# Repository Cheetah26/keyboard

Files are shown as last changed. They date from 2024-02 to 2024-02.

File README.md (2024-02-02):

# keyboard
My fully custom split keyboard

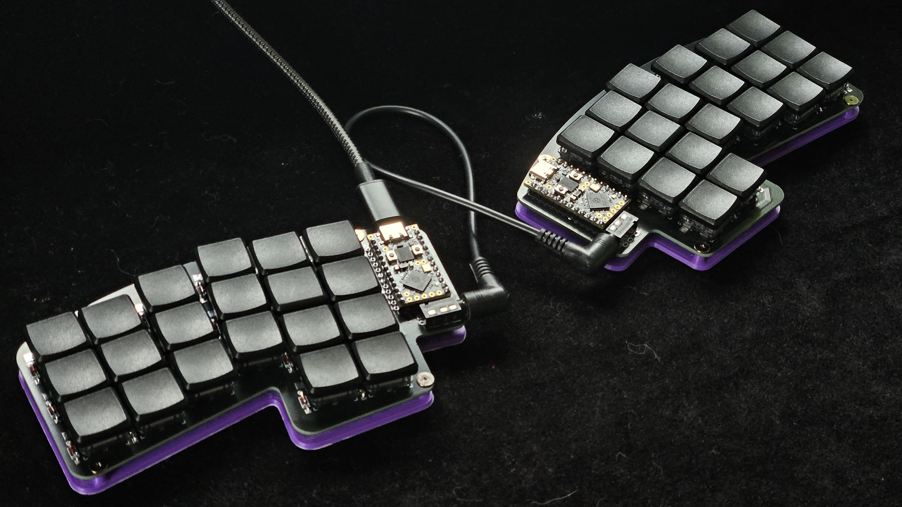
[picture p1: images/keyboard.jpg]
keyboard glamor shot


## Features
- 40 key split layout
- dual rp2040 microcontrollers
- [kmk](http://kmkfw.io) firmware
- stenography layer for [plover](http://www.openstenoproject.org/)
- 3d printed base

## Background / design 
After years of wanting an ergonomic split keyboard but never seeing one that perfectly matched what I imagined in my mind, I decided to design and build my own!

I started completely from scratch by putting my hand on a sheet of paper and just seeing where my fingers liked to be. From there I made a layout based on where keys could actually go, and iterated until things really felt right.

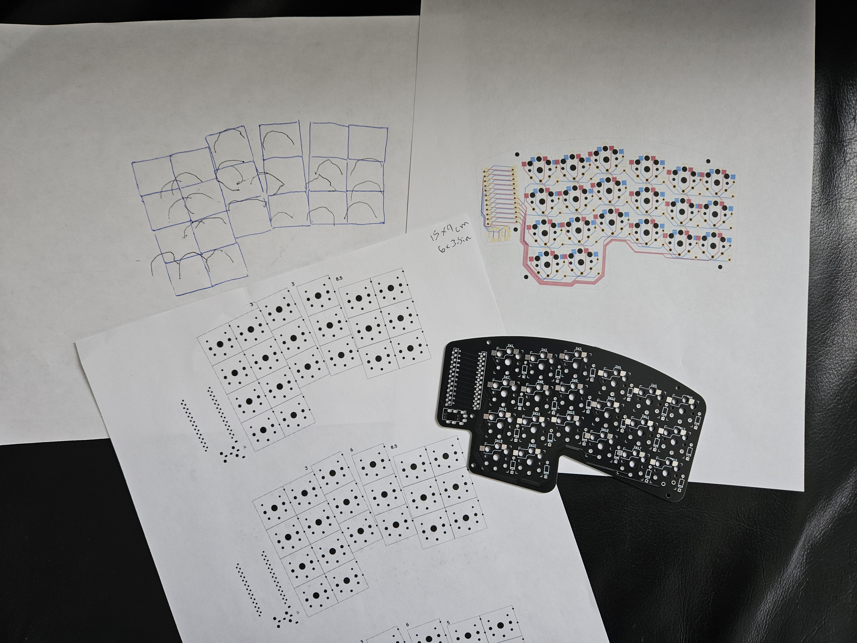
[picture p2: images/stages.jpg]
paper printouts of my PCB design at various stages next to the final PCB


I laid out the PCB according to this design, ordered all the parts, and anxiously waited to find out what I messed up. Since this was my first time designing a PCB, fist time programming a microcontroller, and first big soldering project, I 100% expected something to go wrong. To my surprise, the only issue was that I forgot to account for the size of the jack connecting each half. After a little sanding, everything went together perfectly and now I couldn't be happier with it.

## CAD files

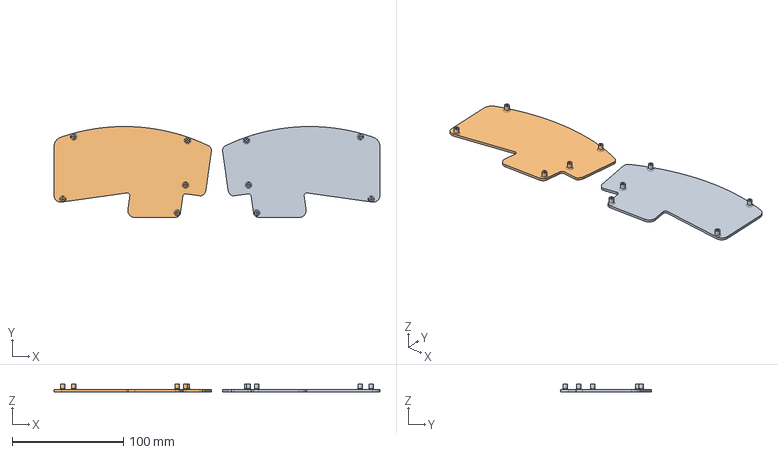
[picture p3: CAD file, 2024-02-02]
base/base.step
293.7 x 81.9 x 7.00 mm

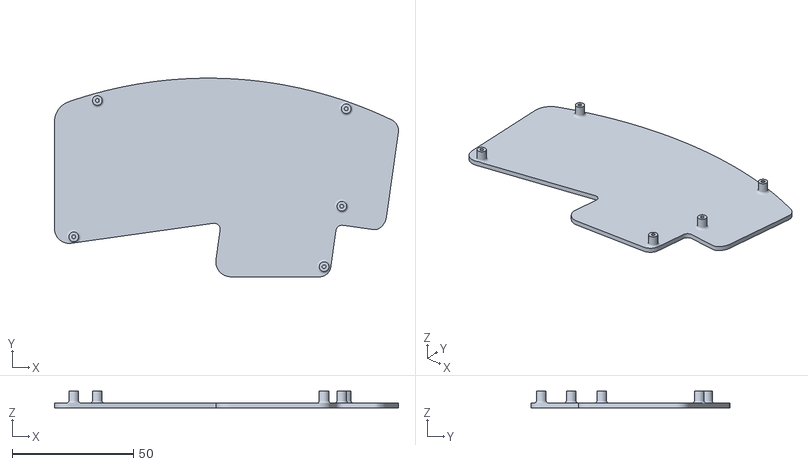
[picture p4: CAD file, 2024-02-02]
base/exports/Left.stl
141.8 x 81.9 x 7.00

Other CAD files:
base/exports/Right.stl

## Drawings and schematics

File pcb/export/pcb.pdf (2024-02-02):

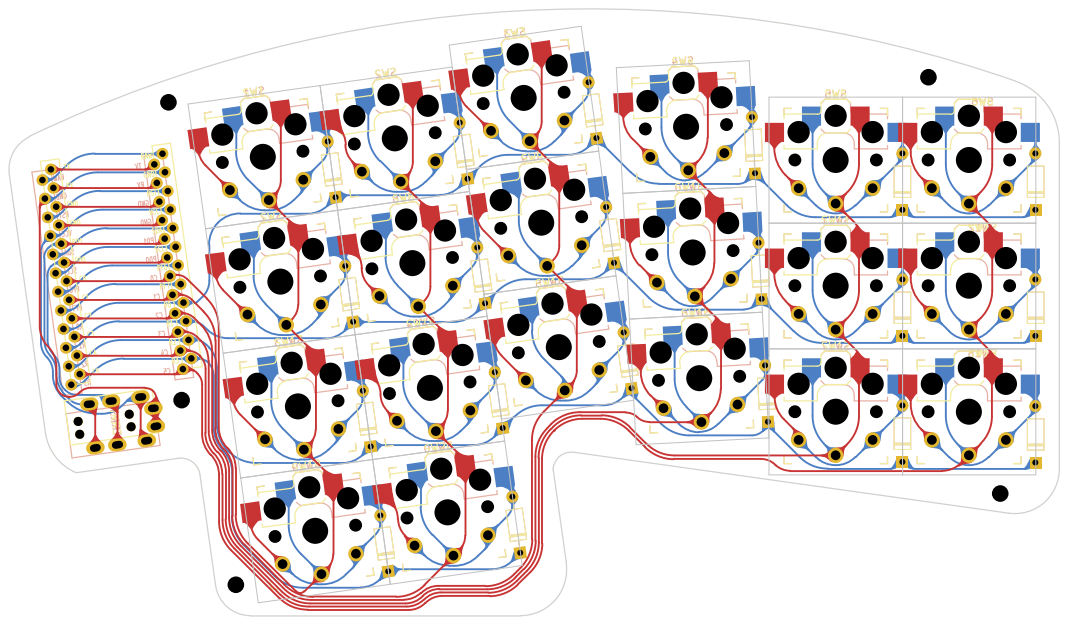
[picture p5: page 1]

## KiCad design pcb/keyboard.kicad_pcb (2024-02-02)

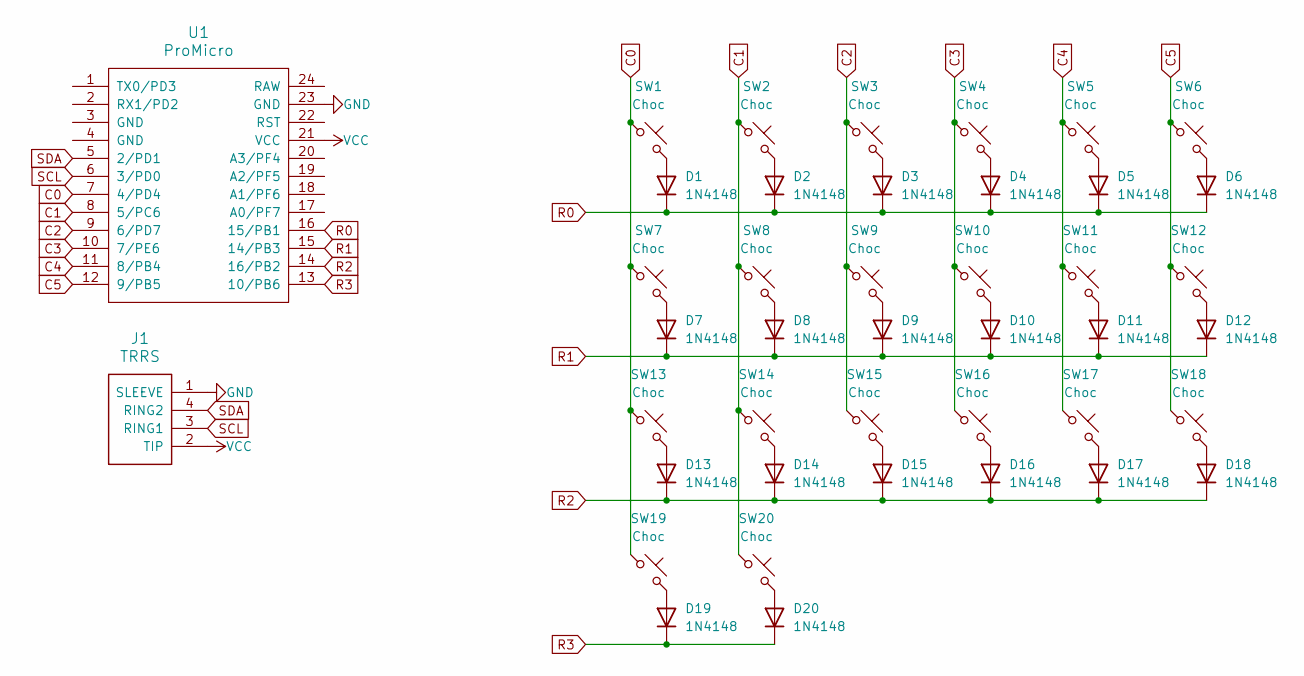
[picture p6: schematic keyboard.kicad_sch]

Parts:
D1, D2, D3, D4, D5, D6, D7, D8, D9, D10, D11, D12, D13, D14, D15, D16, D17, D18, D19, D20: 1N4148; Diode
J1: TRRS; PJ320-A_TRRS
SW1, SW2, SW3, SW4, SW5, SW6, SW7, SW8, SW9, SW10, SW11, SW12, SW13, SW14, SW15, SW16, SW17, SW18, SW19, SW20: Choc; Kailh_socket_PG1350_optional_reversible_outline
U1: ProMicro

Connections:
C0: SW1.1, SW7.1, SW13.1, SW19.1, U1.7 (4/PD4)
C1: SW2.1, SW8.1, SW14.1, SW20.1, U1.8 (5/PC6)
C2: SW3.1, SW9.1, SW15.1, U1.9 (6/PD7)
C3: SW4.1, SW10.1, SW16.1, U1.10 (7/PE6)
C4: SW5.1, SW11.1, SW17.1, U1.11 (8/PB4)
C5: SW6.1, SW12.1, SW18.1, U1.12 (9/PB5)
GND: J1.1 (SLEEVE), U1.23 (GND)
unnamed: D1.2 (A), SW1.2
unnamed: D2.2 (A), SW2.2
unnamed: D3.2 (A), SW3.2
unnamed: D4.2 (A), SW4.2
unnamed: D5.2 (A), SW5.2
unnamed: D6.2 (A), SW6.2
unnamed: D7.2 (A), SW7.2
unnamed: D8.2 (A), SW8.2
unnamed: D9.2 (A), SW9.2
unnamed: D10.2 (A), SW10.2
unnamed: D11.2 (A), SW11.2
unnamed: D12.2 (A), SW12.2
unnamed: D13.2 (A), SW13.2
unnamed: D14.2 (A), SW14.2
unnamed: D15.2 (A), SW15.2
unnamed: D16.2 (A), SW16.2
unnamed: D17.2 (A), SW17.2
unnamed: D18.2 (A), SW18.2
unnamed: D19.2 (A), SW19.2
unnamed: D20.2 (A), SW20.2
R0: D1.1 (K), D2.1 (K), D3.1 (K), D4.1 (K), D5.1 (K), D6.1 (K), U1.16 (15/PB1)
R1: D7.1 (K), D8.1 (K), D9.1 (K), D10.1 (K), D11.1 (K), D12.1 (K), U1.15 (14/PB3)
R2: D13.1 (K), D14.1 (K), D15.1 (K), D16.1 (K), D17.1 (K), D18.1 (K), U1.14 (16/PB2)
R3: D19.1 (K), D20.1 (K), U1.13 (10/PB6)
SCL: J1.3 (RING1), U1.6 (3/PD0)
SDA: J1.4 (RING2), U1.5 (2/PD1)
VCC: J1.2 (TIP), U1.21 (VCC)

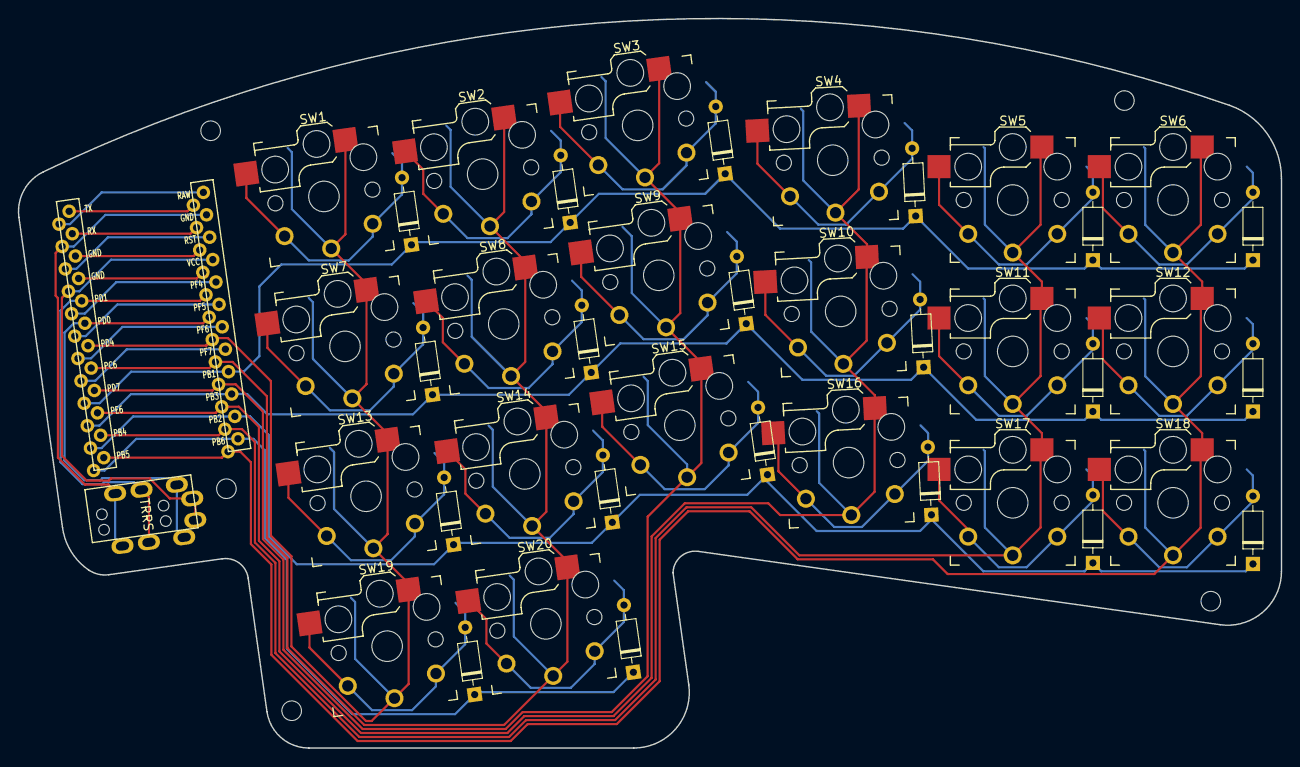
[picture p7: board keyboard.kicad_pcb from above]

Board: 2 copper layers, 141.8 x 81.9 mm, 42 parts (0 on the bottom side), 34 nets.

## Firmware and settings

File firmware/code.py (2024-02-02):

import board

from kmk.kmk_keyboard import KMKKeyboard
from kmk.scanners import DiodeOrientation
from kmk.keys import KC

keyboard = KMKKeyboard()

keyboard.col_pins = (board.GP9, board.GP8, board.GP7, board.GP6, board.GP5, board.GP4)
keyboard.row_pins = (board.GP22, board.GP20, board.GP23, board.GP21)
keyboard.diode_orientation = DiodeOrientation.COL2ROW

from kmk.modules.split import Split, SplitType
split = Split(
    split_flip=True,
    split_side=None,
    split_type=SplitType.UART,
    split_target_left=True,
    uart_interval=20,
    data_pin=board.GP2,
    data_pin2=board.GP3,
    uart_flip=True,
    use_pio=True,
)
keyboard.modules.append(split)

from kmk.modules.holdtap import HoldTap
keyboard.modules.append(HoldTap())
SPC_LSFT = KC.HT(KC.SPC, KC.LSFT)
ENT_LGUI = KC.HT(KC.ENT, KC.LGUI)

from kmk.modules.layers import Layers
keyboard.modules.append(Layers())
TO_BASE = KC.TO(0)
TO_STENO = KC.TO(3)
MO_NUM = KC.MO(1)
MO_MISC = KC.MO(2)

from kmk.modules.combos import Combos, Chord
combos = Combos(
  combos=[
        Chord((SPC_LSFT, ENT_LGUI), KC.LALT),
        Chord((MO_NUM, KC.BSPC), MO_MISC)
])
keyboard.modules.append(combos)

from kmk.extensions.media_keys import MediaKeys
keyboard.extensions.append(MediaKeys())

from kmk.modules.steno import Steno
keyboard.modules.append(Steno())

keyboard.keymap = [
    [ # Base layer
        KC.ESC, KC.Q, KC.W, KC.E, KC.R,     KC.T,         KC.Y,     KC.U,     KC.I,    KC.O,   KC.P,    KC.LBRC,
        KC.TAB, KC.A, KC.S, KC.D, KC.F,     KC.G,         KC.H,     KC.J,     KC.K,    KC.L,   KC.QUOT, KC.SCLN,
        KC.LCTL,KC.Z, KC.X, KC.C, KC.V,     KC.B,         KC.N,     KC.M,     KC.COMM, KC.DOT, KC.SLSH, KC.RBRC,
        KC.NO,  KC.NO,KC.NO,KC.NO,MO_NUM, KC.BSPC,      SPC_LSFT, ENT_LGUI, KC.NO,KC.NO,KC.NO,KC.NO,
    ],
    [ # Numbers / navigation
        KC.TRNS, KC.GRAVE,  KC.N6, KC.N5, KC.N4, KC.MINS,            KC.HOME, KC.PGDOWN, KC.PGUP, KC.END, KC.NO, KC.NO,
        TO_STENO, KC.EQL, KC.N3, KC.N2, KC.N1, KC.N0,              KC.LEFT, KC.DOWN, KC.UP, KC.RIGHT, KC.NO, KC.NO,
        KC.TRNS, KC.BSLASH,  KC.N9, KC.N8, KC.N7, KC.PDOT,            KC.NO,   KC.NO,   KC.NO, KC.NO,   KC.NO, KC.NO,
        KC.NO,   KC.NO,  KC.NO, KC.NO, KC.TRNS,KC.TRNS,           KC.TRNS, KC.TRNS, KC.NO, KC.NO,    KC.NO, KC.NO,
    ],
    [ # Misc.
        KC.TRNS, KC.NO,  KC.F6, KC.F5, KC.F4, KC.F10,            KC.HOME, KC.PGDOWN, KC.PGUP, KC.END,    KC.NO, KC.NO,
        KC.TRNS, KC.NO, KC.F3, KC.F2, KC.F1, KC.F11,            KC.MPRV, KC.VOLD, KC.VOLU, KC.MNXT,KC.MPLY, KC.NO,
        KC.TRNS, KC.NO,  KC.F9, KC.F8, KC.F7, KC.F12,            KC.NO,   KC.NO,   KC.NO, KC.NO,   KC.NO, KC.NO,
        KC.NO,   KC.NO,  KC.NO, KC.NO, KC.TRNS,KC.TRNS,          KC.TRNS, KC.TRNS, KC.NO, KC.NO,    KC.NO, KC.NO,
    ],
    [ # Steno
        KC.ESC, KC.STN_LS1, KC.STN_LT, KC.STN_LP, KC.STN_LH, KC.NO,       KC.STN_AS3, KC.STN_RF, KC.STN_RP, KC.STN_RL, KC.STN_RT, KC.STN_RD,
        TO_BASE, KC.STN_LS2, KC.STN_LK, KC.STN_LW, KC.STN_LR, KC.NO,       KC.STN_AS4, KC.STN_RR, KC.STN_RB, KC.STN_RG, KC.STN_RS, KC.STN_RZ,
        KC.NO, KC.NO,      KC.NO,     KC.NO,     KC.NO,     KC.NO,       KC.NO,     KC.NO,     KC.NO,     KC.NO,     KC.NO,     KC.NO,
        KC.NO,   KC.NO,      KC.NO,     KC.NO,     KC.STN_A,  KC.STN_O,    KC.STN_E,  KC.STN_U,  KC.NO,     KC.NO,     KC.NO,     KC.NO,
    ]
]

if __name__ == '__main__':
    keyboard.go()

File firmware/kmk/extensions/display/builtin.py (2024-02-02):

    return {
            'brightness': self.brightness,
            'brightness_step': self.brightness_step,
            'brightness_limit': self.brightness_limit,
        }

    def on_runtime_enable(self, sandbox):
        return

    def on_runtime_disable(self, sandbox):
        return

    def during_bootup(self, sandbox):
        '''Light up every single led once for 200 ms'''
        for i in range(self._led_count + 2):
            if i < self._led_count:
                self._leds[i].duty_cycle = int(self.brightness / 100 * 65535)
            i_off = i - 2
            if i_off >= 0 and i_off < self._led_count:
                self._leds[i_off].duty_cycle = int(0)
            time.s
